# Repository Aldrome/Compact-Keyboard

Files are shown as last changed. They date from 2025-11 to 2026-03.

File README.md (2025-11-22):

# Compact Piano Keyboard with DSP and MIDI functions

Schematic link
https://drive.google.com/drive/folders/1MW6RK4cLdNylEYujYAkNW5wjjUnl7ojT?usp=drive_link

Most piano keyboards that musicians use are full scale, which causes problems for composing or playing
in places that lack the space or accessibility, since it is made for performance. This keyboard project has the
focus of minimizing size to something you can fit on a desk and be able to move more freely with it. It will be
more of a MIDI controller and music creation, not as a performance machine.

### Current Objective
	Aldrich: Code general functions and create midi function for 1-3 keys
 	Andrew:  Create a keyboard matrix (48 keys) [Search keyboard matrix for more info]

## Issues to think about:
	- Choosing a microcontroller with the DSP and MIDI capability (Using Teensy 4.1 + Audio Shield Rev D)
	- Handle the keyboard matrix and decide the key amount
	- PCB designing and how to route the I/Os
	- The type of inputs, considering it is a piano

## Planning with steps
	1. Prepare microcontroller for use (solder all pin feet in place)
	2. Test out audio I/O using only the headphones
	3. Prototype a simple synth wave maker using a few buttons
	4. If possible, use a synth wave synthesizer to create a piano sound, maybe more. Else, use audio from free source.
	5. Create a prototype keyboard matrix, and a full scale on KiCad. Also add anti-ghosting using diodes.
	6. Test out potentiometer to divide the input keys to 2 sections.
	7. Add a slider + button for DSP, similar to a mixer.
	8. Depending on the time constraint and resources, print a PCB to handle all these features.

## Additional feature that can be added, though not a priority
	1. A display with UI implementation to decide instrument or maybe change DSP settings.
	2. The input keys by default will be a simple button, similar to a typing keyboard.
	   But if possible, use a sensitivity keyboard using a 2 point detector.
	3. No casings for this project.

Notes: This project will be done in 2 parts for every steps that includes prototyping. One being the physical prototype and
       the other part being the schematic design. After finishing schematic, create a footprint for PCB. Printing a PCB will not
       be a priority, as the demo will mainly be a concept using a prototype. Though we will print a PCB if possible.

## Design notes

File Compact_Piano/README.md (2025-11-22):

# Note
Cannot be compiled here. Must move to where your sketchbook folder is in and must download the required libraries.
Use this only for copy pasting.

## Boards
```
Teensyduino
```
## Libraries
```
ILI9341_t3n
```

## USB Type
```
Serial + MIDI + Audio
```

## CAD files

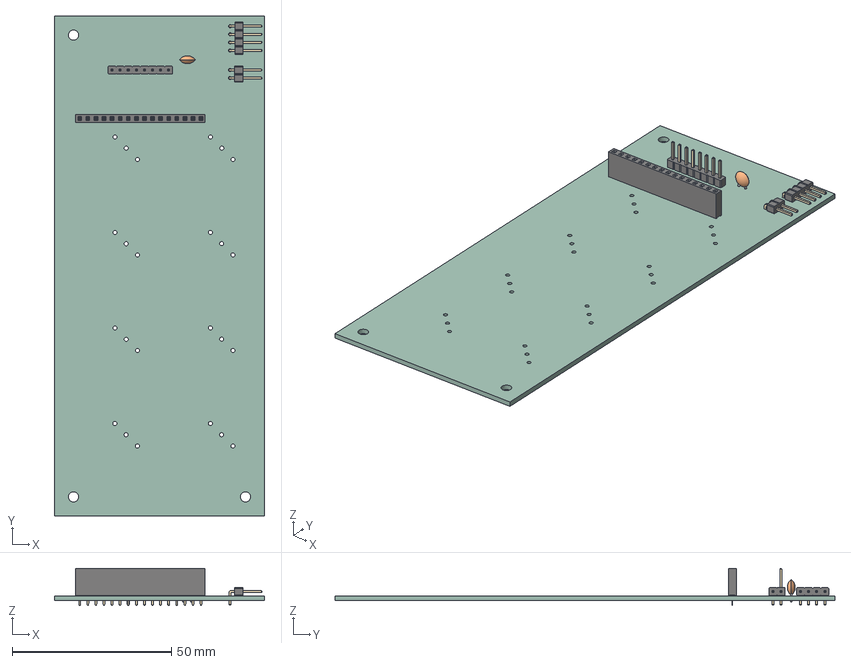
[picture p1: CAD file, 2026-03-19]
Compact Keyboard Schem/Potentiometer+MUX/Potentiometer+MUX.step
66.0 x 157.0 x 11.6 mm
PinHeader_1x08_P2.54mm_Vertical
PinHeader_1x04_P2.54mm_Horizontal
C_Disc_D5.0mm_W2.5mm_P2.50mm
PinHeader_1x02_P2.54mm_Horizontal
PinSocket_1x16_P2.54mm_Vertical
Potentiometer+MUX_PCB

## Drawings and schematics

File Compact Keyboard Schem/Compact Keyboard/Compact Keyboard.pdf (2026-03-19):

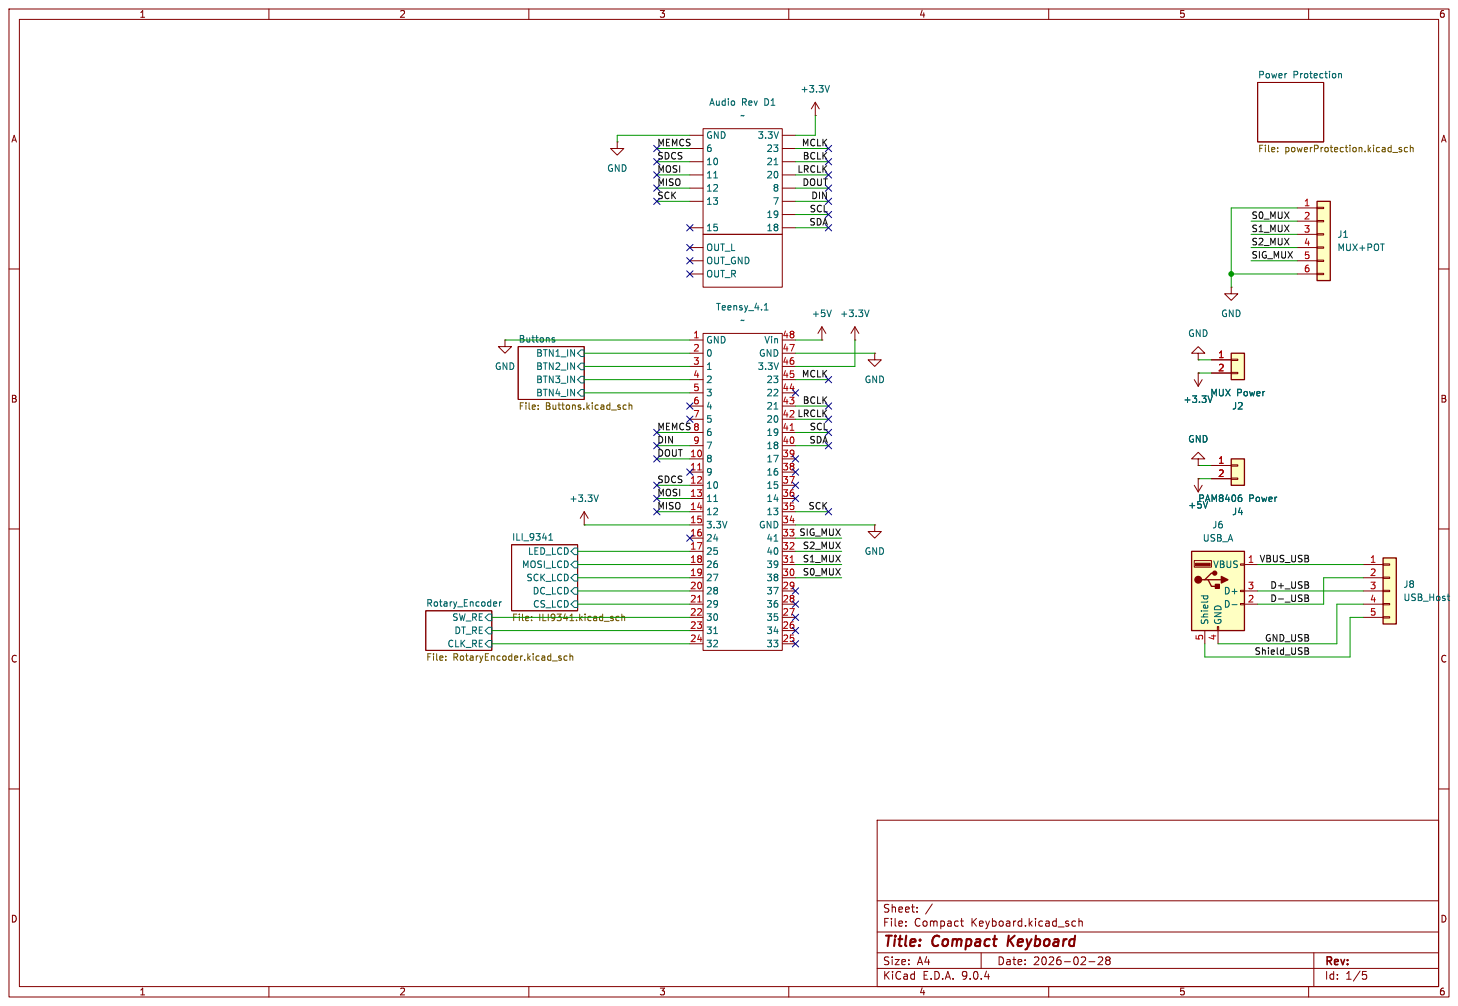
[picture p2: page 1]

Power Protection File: powerProtection.kicad_sch CLK_RE DT_RE
SW_RE Rotary_Encoder File: RotaryEncoder.kicad_sch BTN1_IN

SCL SDA DIN MEMCS

J2 MUX Power GND GND 1

Id: 1/5 Title: Compact Keyboard

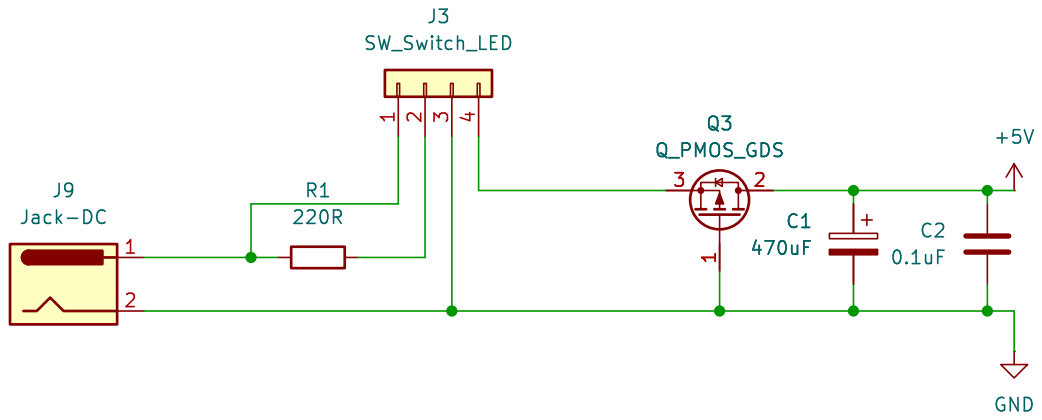
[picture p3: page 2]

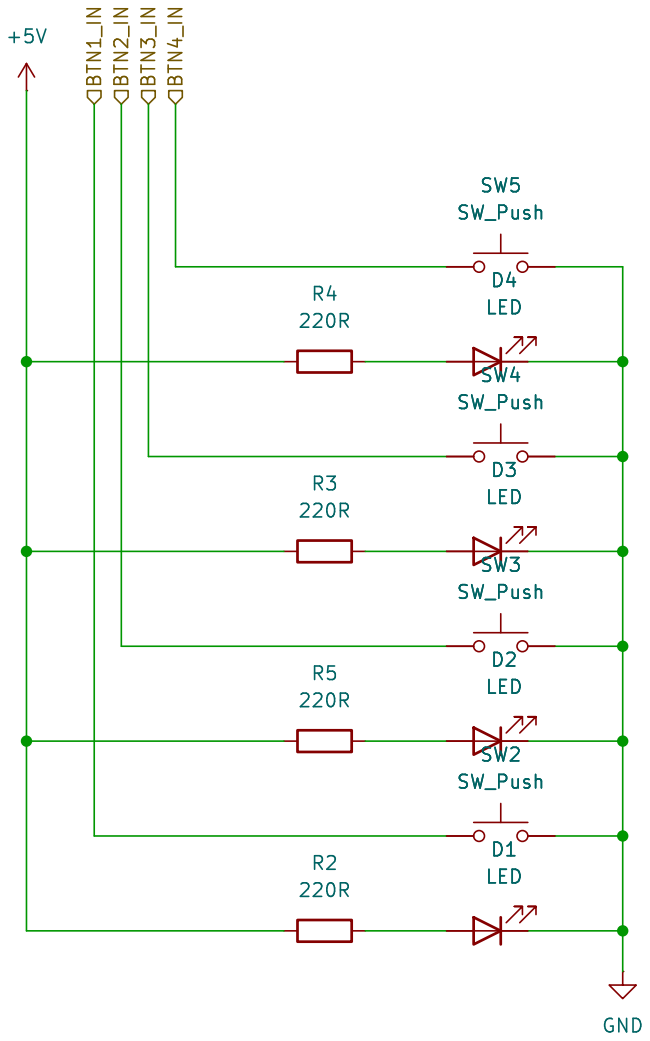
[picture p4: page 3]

Id: 3/5 Title: File: Buttons.kicad_sch Sheet: /Buttons/ SW2 SW_Push D1

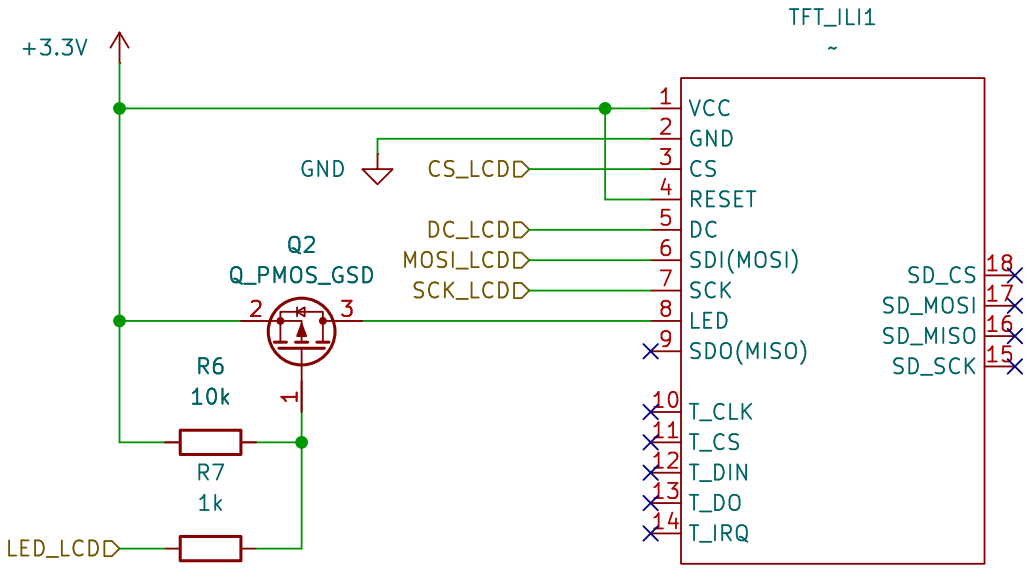
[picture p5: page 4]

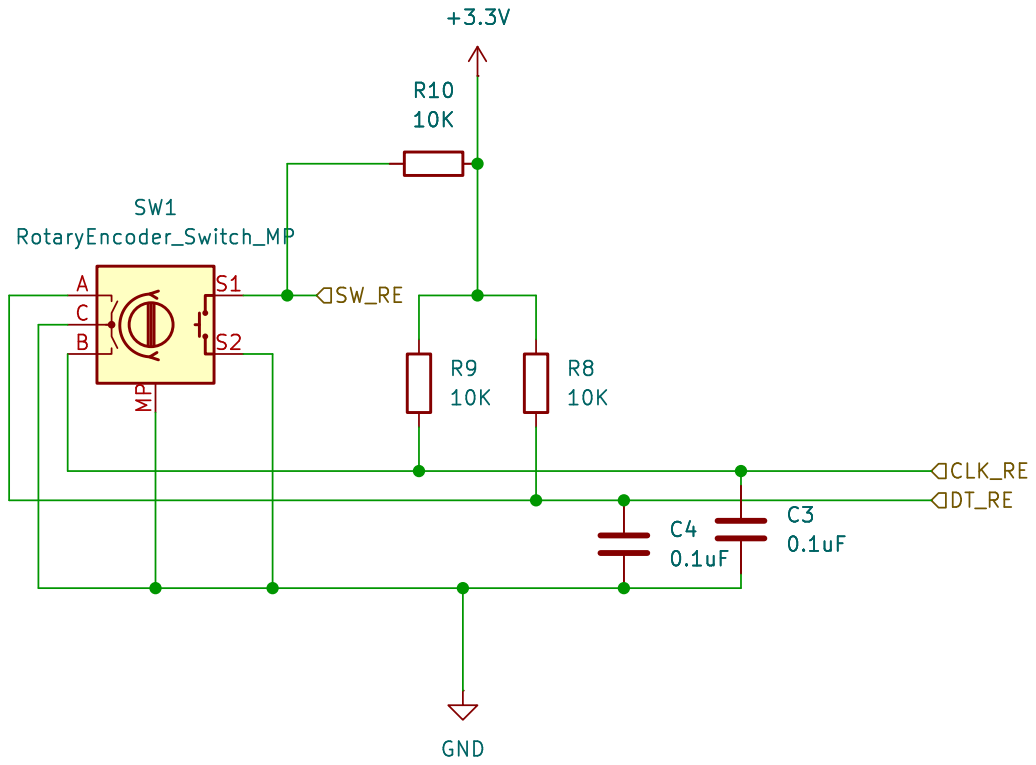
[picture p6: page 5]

Id: 5/5 Title: File: RotaryEncoder.kicad_sch Sheet: /Rotary_Encoder/

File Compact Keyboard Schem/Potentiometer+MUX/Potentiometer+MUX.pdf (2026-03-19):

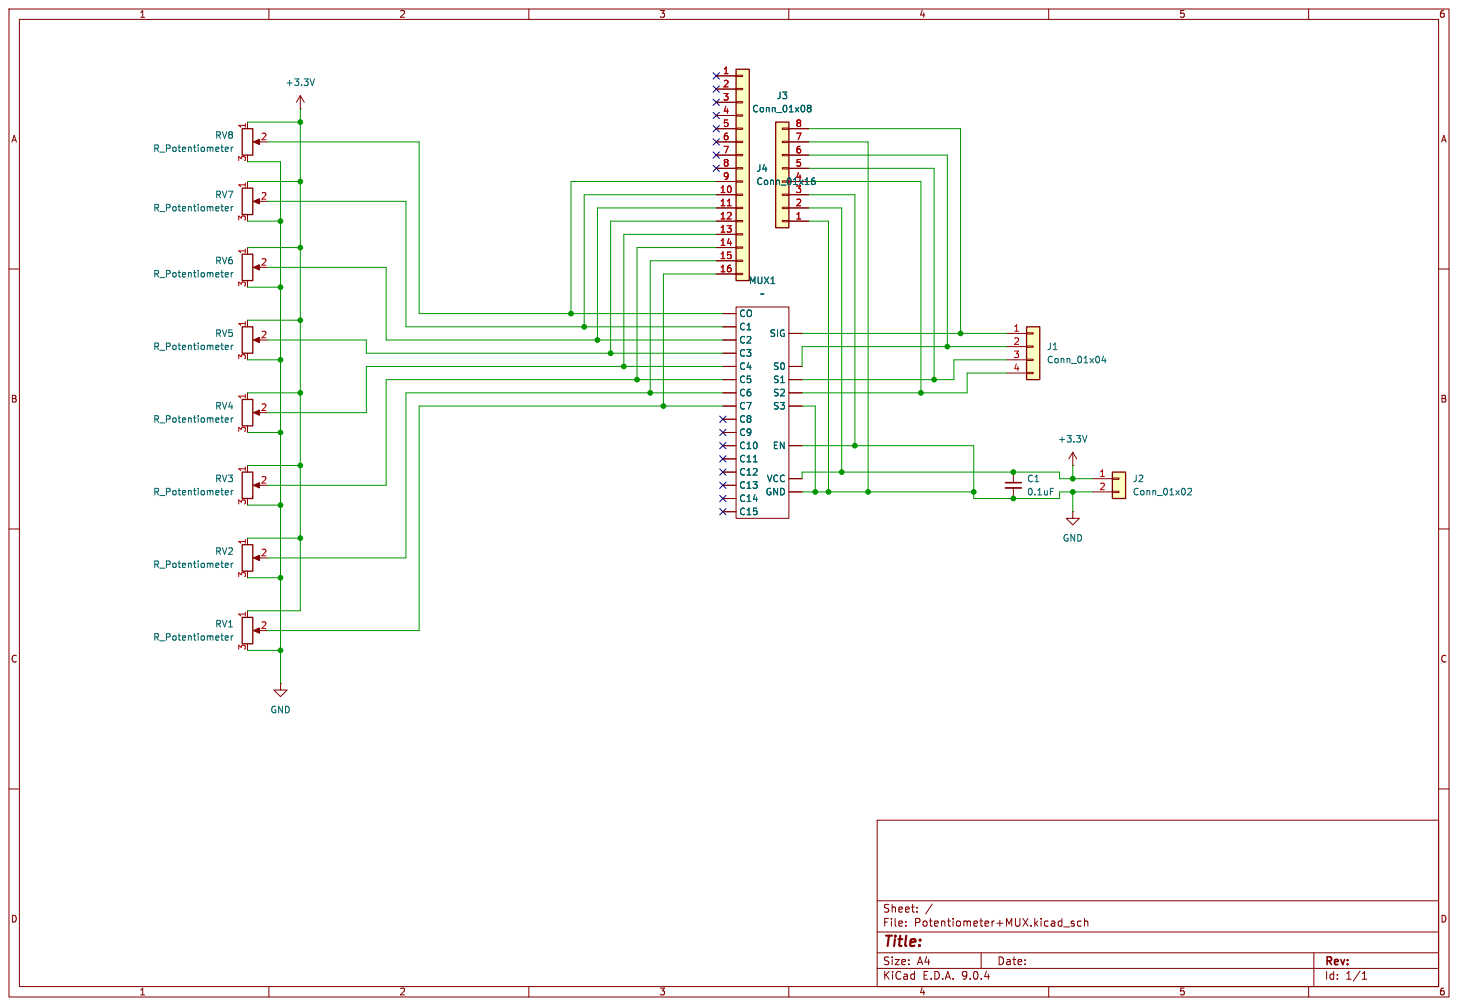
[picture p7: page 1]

Id: 1/1 Title: File: Potentiometer+MUX.kicad_sch Sheet: / 12345678

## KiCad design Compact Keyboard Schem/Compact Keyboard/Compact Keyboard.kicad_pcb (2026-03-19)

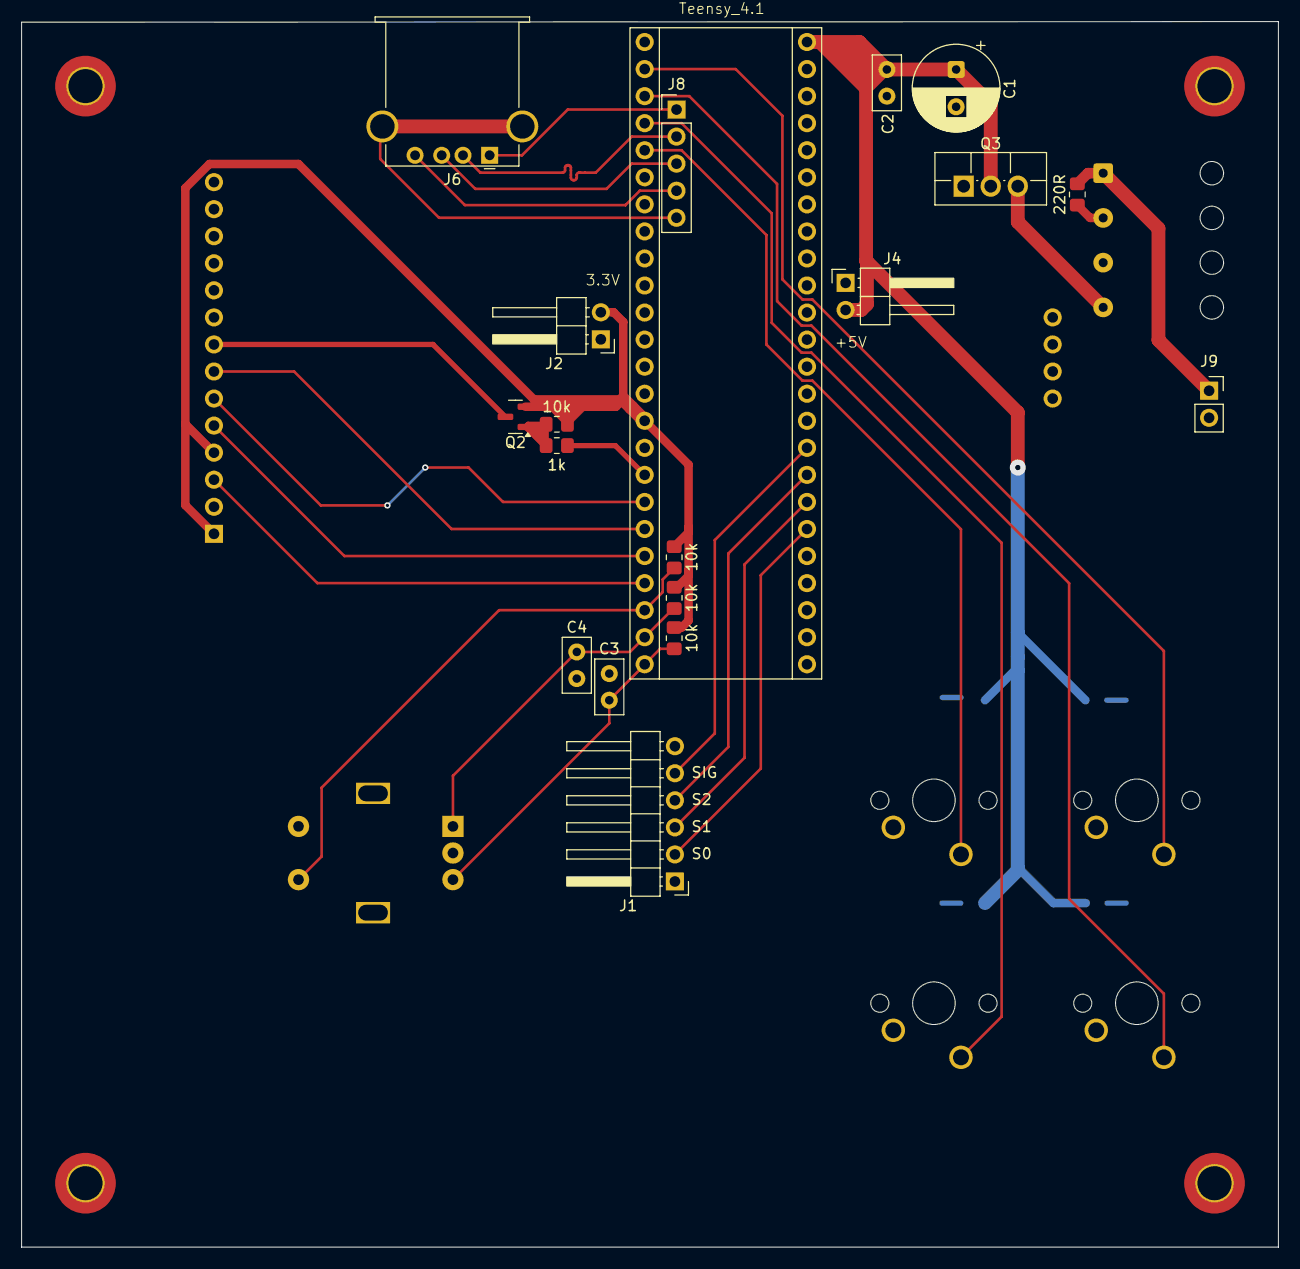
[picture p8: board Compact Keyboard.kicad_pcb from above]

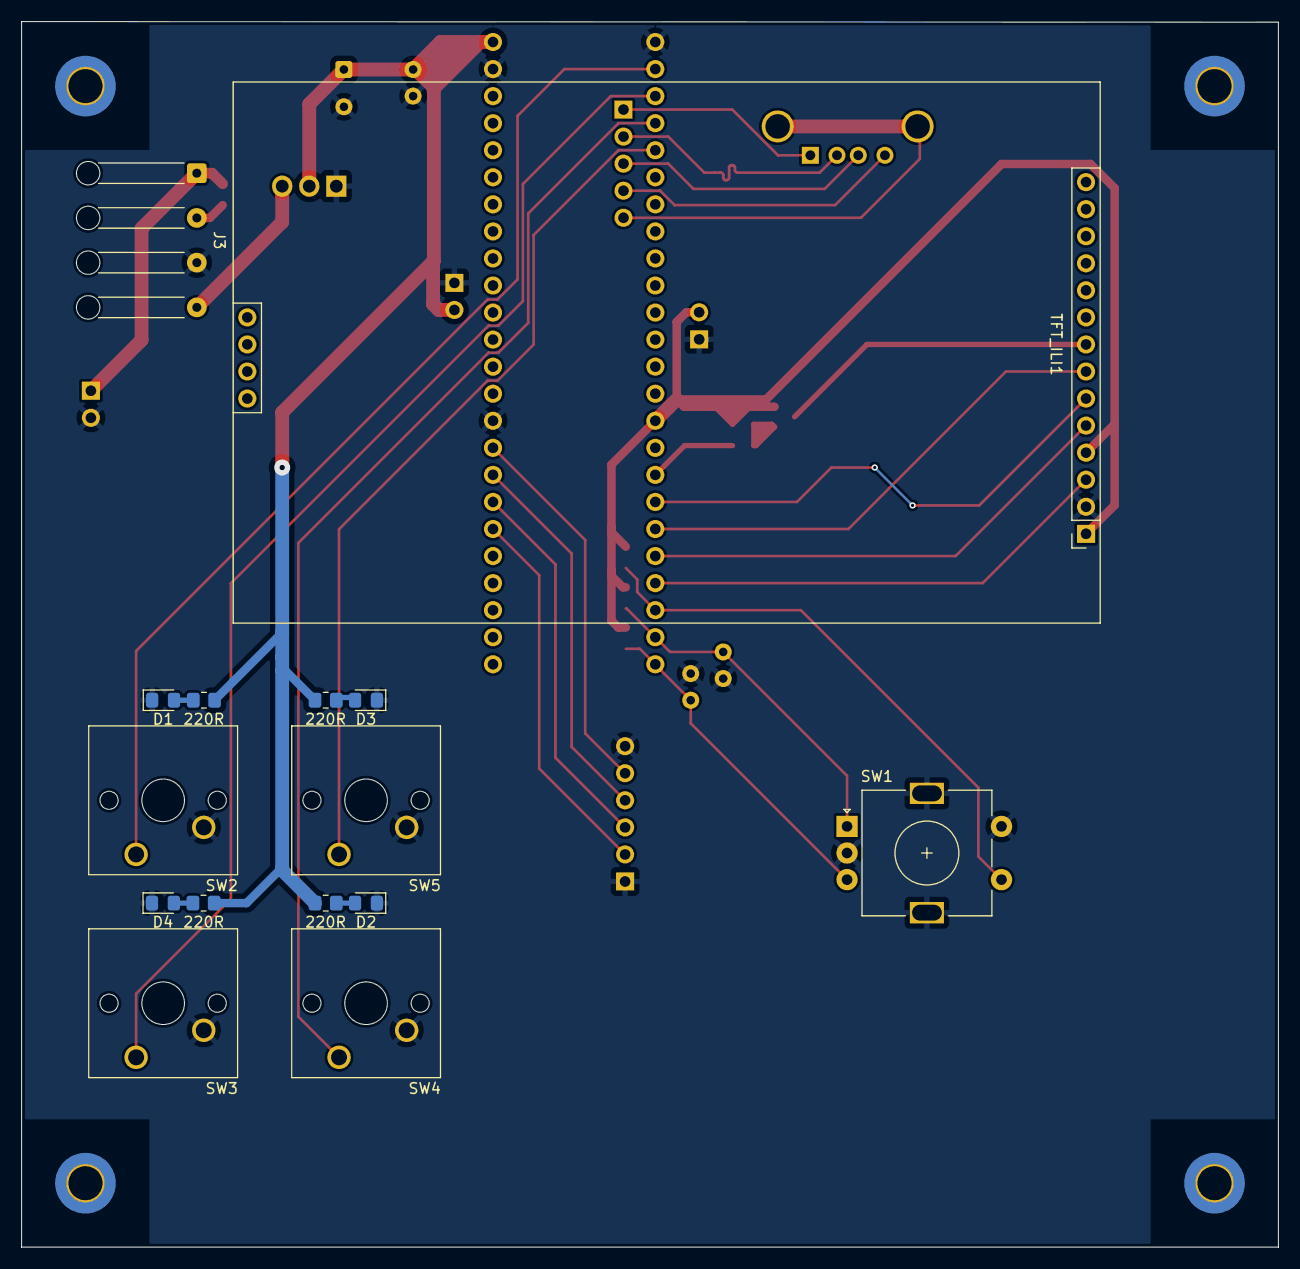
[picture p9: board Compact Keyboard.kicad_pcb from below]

Board: 2 copper layers, 118.0 x 115.1 mm, 34 parts (15 on the bottom side), 33 nets.

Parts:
1k: 1k; R_0805_2012Metric_Pad1.20x1.40mm_HandSolder
10k, 10k#2, 10k#4: 10K; R_0805_2012Metric_Pad1.20x1.40mm_HandSolder
10k#3: 10k; R_0805_2012Metric_Pad1.20x1.40mm_HandSolder
220R, 220R#2, 220R#3, 220R#4, 220R#5: 220R; R_0805_2012Metric_Pad1.20x1.40mm_HandSolder
C1: 470uF; CP_Radial_D8.0mm_P3.50mm
C2, C3, C4: 0.1uF; C_Disc_D5.0mm_W2.5mm_P2.50mm
D1, D2, D3, D4: LED; LED_0805_2012Metric_Pad1.15x1.40mm_HandSolder
J1: MUX+POT; PinHeader_1x06_P2.54mm_Horizontal
J2: MUX Power; PinHeader_1x02_P2.54mm_Horizontal
J3: SW_Switch_LED; SolderWire-0.25sqmm_1x04_P4.2mm_D0.65mm_OD1.7mm_Relief
J4: PAM8406 Power; PinHeader_1x02_P2.54mm_Horizontal
J6: USB_A; USB_A_Stewart_SS-52100-001_Horizontal
J8: USB_Host; PinHeader_1x05_P2.54mm_Vertical
J9: Jack-DC; PinSocket_1x02_P2.54mm_Vertical
Q2: Q_PMOS_GSD; SOT-23
Q3: Q_PMOS_GDS; TO-220F-3_Vertical
SW1: RotaryEncoder_Switch_MP; RotaryEncoder_Alps_EC11E-Switch_Vertical_H20mm
SW2, SW3, SW4, SW5: SW_Push; SW_Cherry_MX_1.00u_PCB
TFT_ILI1: ILI9341_TFT
Teensy_4.1: Teensy

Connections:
+3.3V: 10k.1, 10k#2.1, 10k#3.2, 10k#4.2, J2.2, Q2.2 (S), TFT_ILI1.1 (VCC), TFT_ILI1.4 (RESET), Teensy_4.1.15 (3.3V), Teensy_4.1.46 (3.3V)
+5V: 220R#2.2, 220R#3.2, 220R#4.2, 220R#5.2, C1.1, C2.1, J4.2, Q3.2 (D), Teensy_4.1.48 (Vin)
/Buttons/BTN1_IN: SW2.1, Teensy_4.1.2 (0)
/Buttons/BTN2_IN: SW3.1, Teensy_4.1.3 (1)
/Buttons/BTN3_IN: SW4.1, Teensy_4.1.4 (2)
/Buttons/BTN4_IN: SW5.1, Teensy_4.1.5 (3)
/D+_USB: J6.3 (D+), J8.3
/D-_USB: J6.2 (D-), J8.2
/GND_USB: J6.4 (GND), J8.4
/ILI_9341/CS_LCD: TFT_ILI1.3 (CS), Teensy_4.1.21 (29)
/ILI_9341/DC_LCD: TFT_ILI1.5 (DC), Teensy_4.1.20 (28)
/ILI_9341/LED_LCD: 1k.2, Teensy_4.1.17 (25)
/ILI_9341/MOSI_LCD: TFT_ILI1.6 (SDI(MOSI)), Teensy_4.1.18 (26)
/ILI_9341/SCK_LCD: TFT_ILI1.7 (SCK), Teensy_4.1.19 (27)
/Rotary_Encoder/CLK_RE: 10k.2, C3.1, SW1.B, Teensy_4.1.24 (32)
/Rotary_Encoder/DT_RE: 10k#2.2, C4.1, SW1.A, Teensy_4.1.23 (31)
/Rotary_Encoder/SW_RE: 10k#4.1, SW1.S1, Teensy_4.1.22 (30)
/S0_MUX: J1.2, Teensy_4.1.30 (38)
/S1_MUX: J1.3, Teensy_4.1.31 (39)
/S2_MUX: J1.4, Teensy_4.1.32 (40)
/SIG_MUX: J1.5, Teensy_4.1.33 (41)
/Shield_USB: J6.5 (Shield), J8.5
/VBUS_USB: J6.1 (VBUS), J8.1
GND: C1.2, C2.2, C3.2, C4.2, D1.1 (K), D2.1 (K), D3.1 (K), D4.1 (K), J1.1, J1.6, J2.1, J3.3, J4.1, J9.2, Q3.1 (G), SW1.C, SW1.MP, SW1.S2, SW2.2, SW3.2, SW4.2, SW5.2, TFT_ILI1.2 (GND), Teensy_4.1.1 (GND), Teensy_4.1.34 (GND), Teensy_4.1.47 (GND)
unnamed: 220R#4.1, D1.2 (A)
unnamed: 220R#2.1, D2.2 (A)
unnamed: 220R#5.1, D3.2 (A)
unnamed: 220R#3.1, D4.2 (A)
unnamed: 220R.2, J3.1, J9.1
unnamed: 220R.1, J3.2
unnamed: J3.4, Q3.3 (S)
unnamed: Q2.3 (D), TFT_ILI1.8 (LED)
unnamed: 1k.1, 10k#3.1, Q2.1 (G)

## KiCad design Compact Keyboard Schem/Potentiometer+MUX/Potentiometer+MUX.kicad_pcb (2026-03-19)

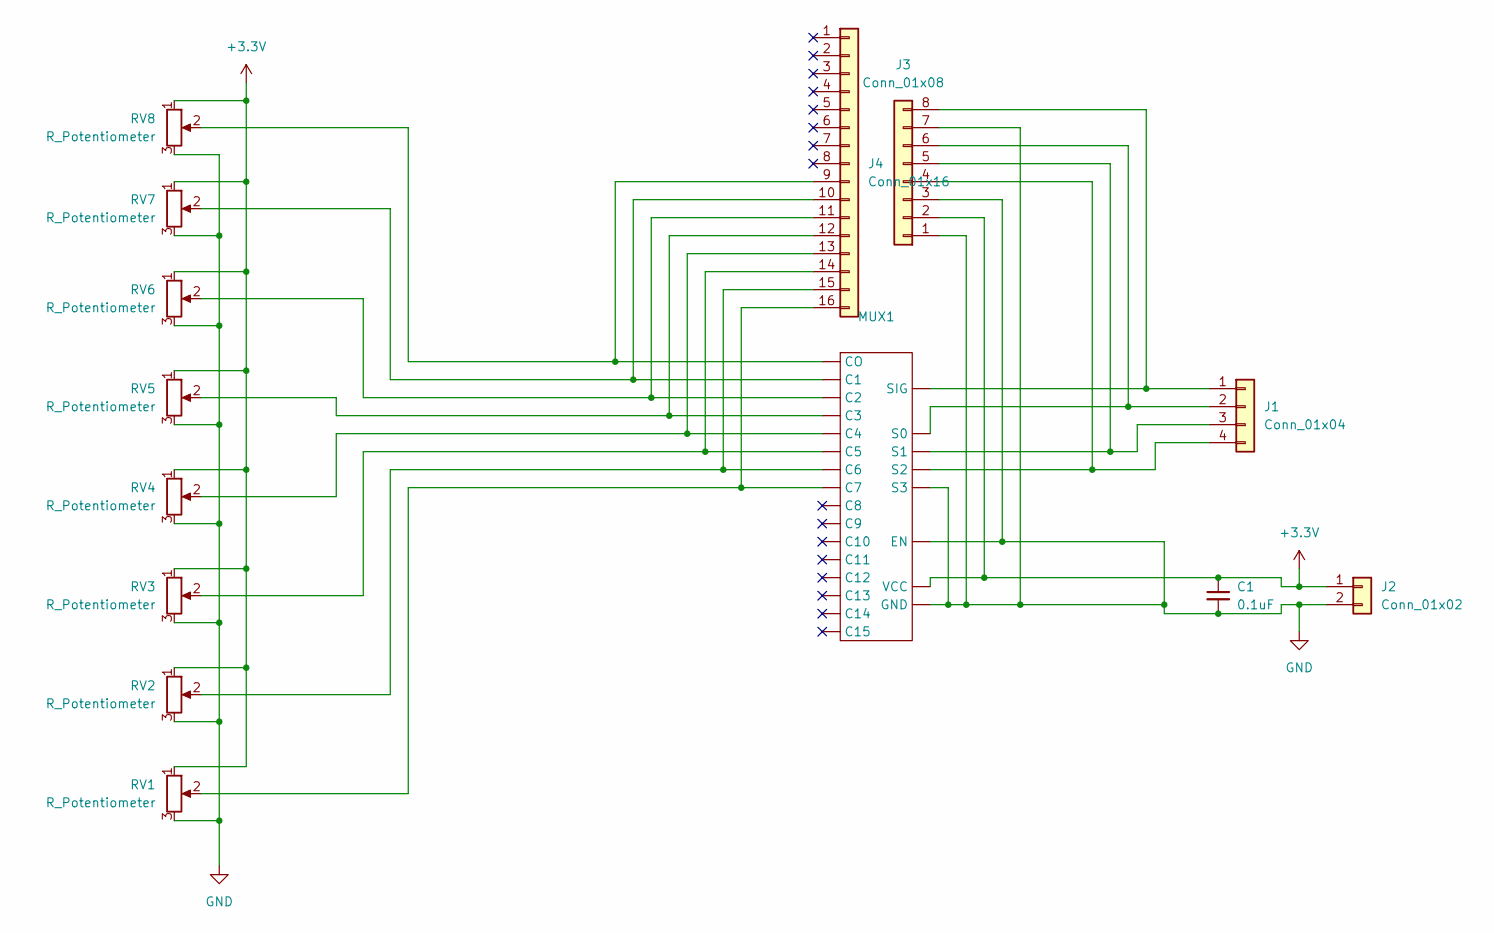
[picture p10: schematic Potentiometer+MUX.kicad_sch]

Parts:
C1: 0.1uF; C_Disc_D5.0mm_W2.5mm_P2.50mm
J1: Conn_01x04; PinHeader_1x04_P2.54mm_Horizontal
J2: Conn_01x02; PinHeader_1x02_P2.54mm_Horizontal
J3: Conn_01x08; PinHeader_1x08_P2.54mm_Vertical
J4: Conn_01x16; PinSocket_1x16_P2.54mm_Vertical
MUX1: (no value)
RV1, RV2, RV3, RV4, RV5, RV6, RV7, RV8: R_Potentiometer; Potentiometer_Omeg_PC16BU_Vertical

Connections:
+3.3V: C1.1, J2.1, J3.2, MUX1., RV1.1, RV2.1, RV3.1, RV4.1, RV5.1, RV6.1, RV7.1, RV8.1
GND: C1.2, J2.2, J3.1, J3.3, J3.7, MUX1., RV1.3, RV2.3, RV3.3, RV4.3, RV5.3, RV6.3, RV7.3, RV8.3
unnamed: J1.1, J3.8, MUX1.
unnamed: J1.2, J3.6, MUX1.
unnamed: J1.3, J3.5, MUX1.
unnamed: J1.4, J3.4, MUX1.
unnamed: J4.9, MUX1., RV8.2
unnamed: J4.10, MUX1., RV7.2
unnamed: J4.11, MUX1., RV6.2
unnamed: J4.12, MUX1., RV5.2
unnamed: J4.13, MUX1., RV4.2
unnamed: J4.14, MUX1., RV3.2
unnamed: J4.15, MUX1., RV2.2
unnamed: J4.16, MUX1., RV1.2

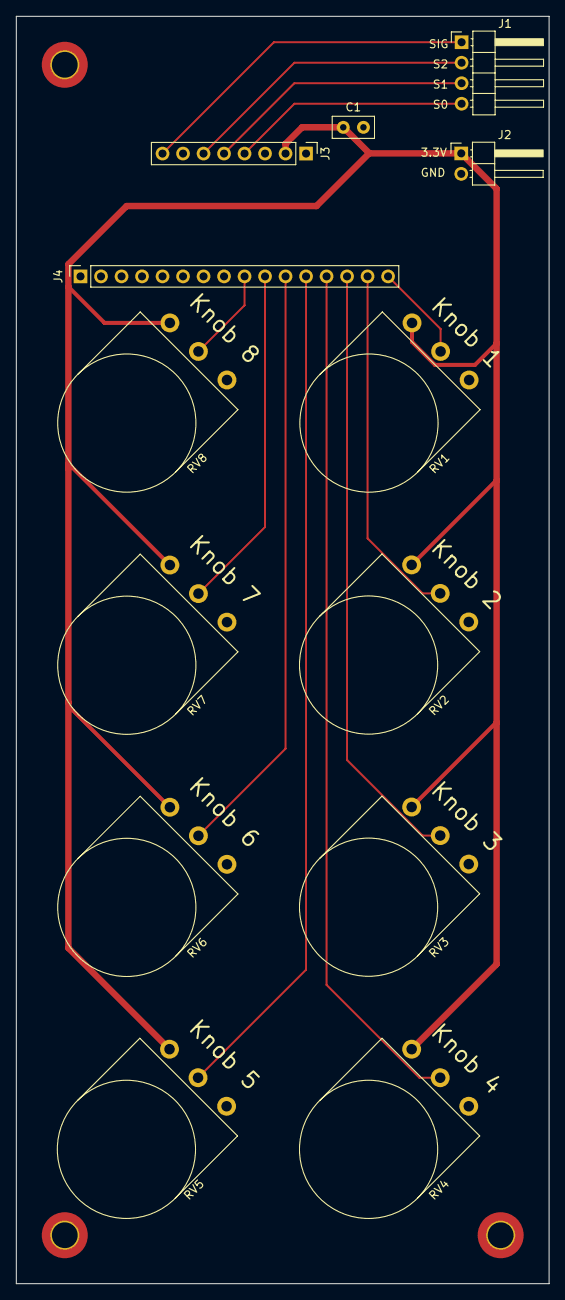
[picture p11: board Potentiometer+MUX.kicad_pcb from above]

Board: 2 copper layers, 66.0 x 157.0 mm, 13 parts (0 on the bottom side), 14 nets.

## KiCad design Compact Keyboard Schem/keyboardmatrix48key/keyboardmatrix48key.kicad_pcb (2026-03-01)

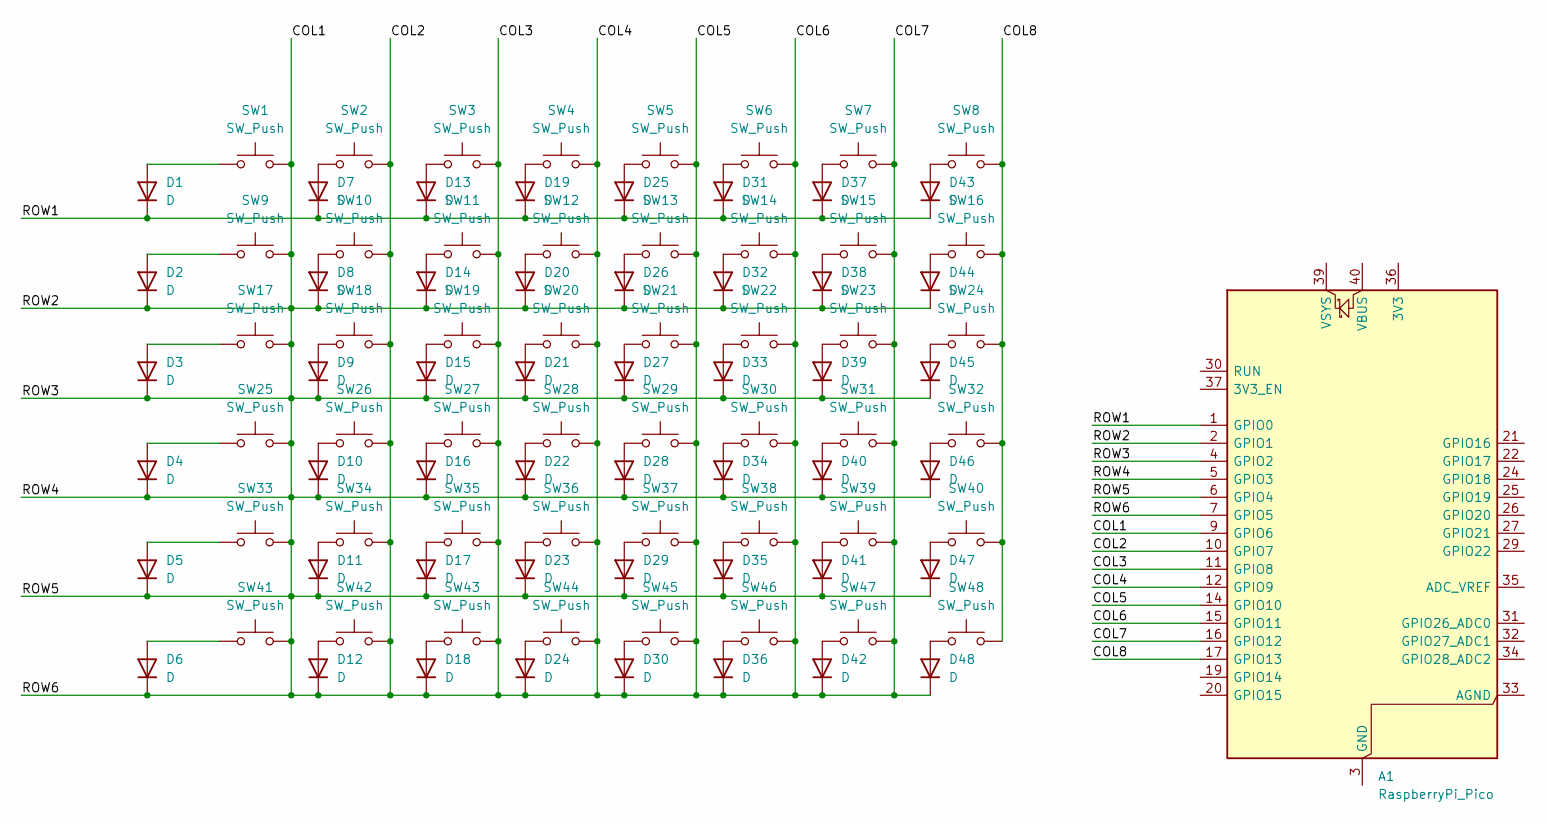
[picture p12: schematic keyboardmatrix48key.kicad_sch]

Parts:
A1: RaspberryPi_Pico; RaspberryPi_Pico_Common_Unspecified
D1, D2, D3, D4, D5, D6, D7, D8, D9, D10, D11, D12, D13, D14, D15, D16, D17, D18, D19, D20, D21, D22, D23, D24, D25, D26, D27, D28, D29, D30, D31, D32, D33, D34, D35, D36, D37, D38, D39, D40, D41, D42, D43, D44, D45, D46, D47, D48: D; D_1206_3216Metric_Pad1.42x1.75mm_HandSolder
SW1, SW2, SW3, SW4, SW5, SW6, SW7, SW8, SW9, SW10, SW11, SW12, SW13, SW14, SW15, SW16, SW17, SW18, SW19, SW20, SW21, SW22, SW23, SW24, SW25, SW26, SW27, SW28, SW29, SW30, SW31, SW32, SW33, SW34, SW35, SW36, SW37, SW38, SW39, SW40, SW41, SW42, SW43, SW44, SW45, SW46, SW47, SW48: SW_Push; SW_Cherry_MX_1.00u_PCB

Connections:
/COL1: A1.2 (GPIO1), A1.4 (GPIO2), A1.5 (GPIO3), A1.6 (GPIO4), A1.7 (GPIO5), A1.9 (GPIO6), A1.10 (GPIO7), A1.11 (GPIO8), A1.12 (GPIO9), A1.14 (GPIO10), A1.15 (GPIO11), A1.16 (GPIO12), D2.1 (K), D3.1 (K), D4.1 (K), D5.1 (K), D6.1 (K), D8.1 (K), D9.1 (K), D10.1 (K), D11.1 (K), D12.1 (K), D14.1 (K), D15.1 (K), D16.1 (K), D17.1 (K), D18.1 (K), D20.1 (K), D21.1 (K), D22.1 (K), D23.1 (K), D24.1 (K), D26.1 (K), D27.1 (K), D28.1 (K), D29.1 (K), D30.1 (K), D32.1 (K), D33.1 (K), D34.1 (K), D35.1 (K), D36.1 (K), D38.1 (K), D39.1 (K), D40.1 (K), D41.1 (K), D42.1 (K), D44.1 (K), D45.1 (K), D46.1 (K), D47.1 (K), D48.1 (K), SW1.2, SW2.2, SW3.2, SW4.2, SW5.2, SW6.2, SW7.2, SW9.2, SW10.2, SW11.2, SW12.2, SW13.2, SW14.2, SW15.2, SW17.2, SW18.2, SW19.2, SW20.2, SW21.2, SW22.2, SW23.2, SW25.2, SW26.2, SW27.2, SW28.2, SW29.2, SW30.2, SW31.2, SW33.2, SW34.2, SW35.2, SW36.2, SW37.2, SW38.2, SW39.2, SW41.2, SW42.2, SW43.2, SW44.2, SW45.2, SW46.2, SW47.2
/COL8: A1.17 (GPIO13), SW8.2, SW16.2, SW24.2, SW32.2, SW40.2, SW48.2
/ROW1: A1.1 (GPIO0), D1.1 (K), D7.1 (K), D13.1 (K), D19.1 (K), D25.1 (K), D31.1 (K), D37.1 (K), D43.1 (K)
unnamed: A1.3 (GND), A1.8 (GND), A1.13 (GND), A1.18 (GND), A1.23 (GND), A1.28 (GND), A1.38 (GND)
unnamed: D1.2 (A), SW1.1
unnamed: D2.2 (A), SW9.1
unnamed: D3.2 (A), SW17.1
unnamed: D4.2 (A), SW25.1
unnamed: D5.2 (A), SW33.1
unnamed: D6.2 (A), SW41.1
unnamed: D7.2 (A), SW2.1
unnamed: D8.2 (A), SW10.1
unnamed: D9.2 (A), SW18.1
unnamed: D10.2 (A), SW26.1
unnamed: D11.2 (A), SW34.1
unnamed: D12.2 (A), SW42.1
unnamed: D13.2 (A), SW3.1
unnamed: D14.2 (A), SW11.1
unnamed: D15.2 (A), SW19.1
unnamed: D16.2 (A), SW27.1
unnamed: D17.2 (A), SW35.1
unnamed: D18.2 (A), SW43.1
unnamed: D19.2 (A), SW4.1
unnamed: D20.2 (A), SW12.1
unnamed: D21.2 (A), SW20.1
unnamed: D22.2 (A), SW28.1
unnamed: D23.2 (A), SW36.1
unnamed: D24.2 (A), SW44.1
unnamed: D25.2 (A), SW5.1
unnamed: D26.2 (A), SW13.1
unnamed: D27.2 (A), SW21.1
unnamed: D28.2 (A), SW29.1
unnamed: D29.2 (A), SW37.1
unnamed: D30.2 (A), SW45.1
unnamed: D31.2 (A), SW6.1
unnamed: D32.2 (A), SW14.1
unnamed: D33.2 (A), SW22.1
unnamed: D34.2 (A), SW30.1
unnamed: D35.2 (A), SW38.1
unnamed: D36.2 (A), SW46.1
unnamed: D37.2 (A), SW7.1
unnamed: D38.2 (A), SW15.1
unnamed: D39.2 (A), SW23.1
unnamed: D40.2 (A), SW31.1
unnamed: D41.2 (A), SW39.1
unnamed: D42.2 (A), SW47.1
unnamed: D43.2 (A), SW8.1
unnamed: D44.2 (A), SW16.1
unnamed: D45.2 (A), SW24.1
unnamed: D46.2 (A), SW32.1
unnamed: D47.2 (A), SW40.1
unnamed: D48.2 (A), SW48.1

Board: 2 copper layers, 97 parts (0 on the bottom side), 52 nets, no tracks yet.

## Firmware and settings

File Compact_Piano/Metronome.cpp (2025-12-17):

// Metronome.cpp

#include "Metronome.h"
#include <Arduino.h>
#include <Audio.h>
#include "synth_simple_drum.h"

Metronome* Metronome::instance = nullptr;

Metronome::Metronome(AudioSynthSimpleDrum* drumSynth) : tickSynth(drumSynth) {
     instance = this;
}

void Metronome::begin() {

}

void Metronome::metronomeTickHandler() {
     if (instance != nullptr) {
          instance->tick();
     }
}

void Metronome::setBPM(int bpm) {
     currentBPM = constrain(bpm, 30, 280); 

     float frequencyHz = (float)currentBPM / 60.0f;
     usInterval = (unsigned long)(1000000.0f / frequencyHz);
}

void Metronome::setOffset(int offset) {
     offsetMillis = constrain(offset, -500, 500); 
}

void Metronome::start() {
     if (state != METRONOME_RUNNING) {
          state = METRONOME_RUNNING;

          if (!musicEngineRunning) {
               float frequencyHz = (float)currentBPM / 60.0f;
               usInterval = (unsigned long)(1000000.0f / frequencyHz);
               
               if (!engineRunning) {
                    metronomeTimer.begin(metronomeTickHandler, 1000);
                    engineRunning = true;
                    isFirstBeat = true; // First beat uses offset (even in standalone)
                    Serial.println("Metronome Engine STARTED (Standalone).");
               }
          }
          
          Serial.println("Metronome Sound ENABLED.");
     }
}

void Metronome::stop() {
     if (state != METRONOME_STOPPED) {
          state = METRONOME_STOPPED;

          if (!musicEngineRunning) {
               metronomeTimer.end();
               engineRunning = false;
               Serial.println("Metronome Engine STOPPED (Standalone).");
          }
          
          Serial.println("Metronome Sound DISABLED.");
     }
}

void Metronome::syncStart() {
     musicEngineRunning = true;
     
     if (!engineRunning) {
          metronomeTimer.begin(metronomeTickHandler, 1000); // 1ms tick
          engineRunning = true;
     }
     
     tickTimer = 0;
     isFirstBeat = true;

     Serial.print("Metronome Engine Synced. BPM: ");
     Serial.print(currentBPM);
     Serial.print(", Offset: ");
     Serial.print(offsetMillis);
     Serial.println(" ms. Sound state unchanged.");
}

void Metronome::syncStop() {
     musicEngineRunning = false;
     Serial.println("Metronome Engine Stopped (Music Ended).");

     if (state == METRONOME_STOPPED) {
          if (engineRunning) {
               metronomeTimer.end();
               engineRunning = false;
               Serial.println("Metronome Engine Halted.");
          }
     }
}

void Metronome::loadSongInfo(const SongMetronomeData& data) {
     setBPM(data.bpm);
     setOffset(data.offsetMillis);
     Serial.print("Loaded new song info: ");
     Serial.print(currentBPM);
     Serial.print(" BPM, ");
     Serial.print(offsetMillis);
     Serial.println(" ms offset.");
}

void Metronome::tick() {
     if (!engineRunning) return;

     // Logic:
     // 1. We check if enough time has passed for a beat.
     // 2. Ideally, beat time = usInterval.
     // 3. HOWEVER, for the FIRST beat, we add/subtract the offset.
     
     // Determine the required time for THIS specific beat
     unsigned long targetInterval = usInterval;

     if (isFirstBeat) {
          // Apply offset (convert ms to us)
          // If offset is positive (+50ms), first beat takes LONGER to arrive (delayed start)
          // If offset is negative (-50ms), first beat arrives SOONER
          long offsetUs = (long)offsetMillis * 1000;
          
          if ((long)usInterval + offsetUs > 1000) {
               targetInterval = usInterval + offsetUs;
          } else {
               targetInterval = 1000; // Minimum safety delay (1ms)
          }
     }

     // Check if time has passed (convert tickTimer millis to micros for precision)
     if (tickTimer * 1000 >= targetInterval) {
          
          // --- AUDIO OUTPUT ---
          // Only play if the user has ENABLED the metronome in the menu
          if (state == METRONOME_RUNNING) {
               tickSynth->noteOn();
          }
          // --------------------

          // Reset for next beat
          tickTimer = 0;
          isFirstBeat = false; // Subsequent beats use standard usInterval
     }
}

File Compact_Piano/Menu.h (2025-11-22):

#ifndef MENU_H
#define MENU_H

#include <ILI9341_t3n.h>
#include <ILI9341_fonts.h>
#include <ili9341_t3n_font_Arial.h>

#include "Metronome.h"

enum MenuAction {
     MENU_ACTION_NONE,
     MENU_ACTION_GOTO_MUSIC_PLAYER,
     MENU_ACTION_NEXT_SONG,
     MENU_ACTION_PREV_SONG,
     MENU_ACTION_PLAY_PAUSE,
     MENU_ACTION_GOTO_METRONOME,
     MENU_ACTION_CHANGE_BPM,
     MENU_ACTION_TOGGLE_METRONOME,
     MENU_ACTION_GOTO_SETTINGS,
     MENU_ACTION_GO_BACK,
     MENU_ACTION_GO_HOME
};

enum MenuScreen {
     SCREEN_MAIN,
     SCREEN_MUSIC_PLAYER,
     SCREEN_METRONOME,
     SCREEN_SETTINGS
};

enum PlayerState { PLAYING, PAUSED };

class Menu {
public:
     Menu(ILI9341_t3n& tftDisplay);

     void drawMenu();

     void selectNext();
     void selectPrev();
     MenuAction pressButton();
     
     void drawPeakMeterFrame();
     void updatePeakBars(float leftPeak, float rightPeak);

     void goHome();
     void goBack();

     void setPlayerState(PlayerState state);
     void setMetronomeInfo(MetronomeState state, int bpm);
     void setBPMEditing(bool editing);

private:
     ILI9341_t3n* tft;
     
     MenuScreen currentScreen = SCREEN_MAIN;
     
     // Menu definitions
     static const char* const mainMenuLabels[];
     static const int mainMenuCount;

     static const char* const musicPlayerMenuLabels[];
     static const int musicPlayerMenuCount;

     static const char* const metronomeMenuLabels[];
     static const int metronomeMenuCount;

     static const char* const settingsMenuLabels[];
     static const int settingsMenuCount;

     const char* const* getCurrentMenuItems(int& count);

     int menuIndex = 0;

     int prevLeftHeight = 0;
     int prevRightHeight = 0;

     static constexpr int BAR_WIDTH      = 30;
     static constexpr int BAR_Y_TOP      = 40;
     static constexpr int BAR_Y_LEFT     = 240;
     static constexpr int BAR_Y_RIGHT    = 280;
     static constexpr int BAR_HEIGHT_MAX = 170;

     PlayerState playerState = PAUSED;

     MetronomeState metronomeState = METRONOME_STOPPED;
     int currentBPM = 120;
     bool isBPMEditing = false;
};

#endif

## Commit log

2025-09-06 Starting out
    [Compact Keyboard.kicad_pcb, Compact Keyboard.kicad_sch]
2025-09-18 Symbol file for Teensy 4.1 + Audio Shield Rev D
2025-11-22 Add schematic link to README
    Added schematic link for the Compact Piano Keyboard project.
2025-11-22 Add Teensy 4.1 code
2025-12-17 PAM8403 Amplifier
    [PAM8403 Amplifier.kicad_pcb, PAM8403 Amplifier.kicad_sch]
2025-12-17 Rotary Encoder
    [HW-40 Rotary Encoder.kicad_pcb, HW-40 Rotary Encoder.kicad_sch]
2026-02-26 Layout + Schem Update
    [Potentiometer+MUX.kicad_pcb, Potentiometer+MUX.kicad_sch]
2026-02-26 Finished Layout
    [Potentiometer+MUX.kicad_pcb]
2026-02-27 Smaller MUX, Main Board design
    [Compact Keyboard.kicad_sch, Potentiometer+MUX.kicad_pcb, Potentiometer+MUX.kicad_sch]
2026-02-27 More Inputs for Teensy
    [Compact Keyboard.kicad_sch]
2026-03-05 Cleaned Up Space
    [Buttons.kicad_sch, Compact Keyboard.kicad_pcb, Compact Keyboard.kicad_sch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]
2026-03-05 2nd Move
    [keyboardmatrix48key.kicad_pcb, keyboardmatrix48key.kicad_sch]
2026-03-11 Post PCB Manufacturing
    Specifically the Potentiometer+ MUX
    [Compact Keyboard.kicad_pcb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]
2026-03-19 Pushing Update
    Latest version after PCB printing
    [Buttons.kicad_sch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]
